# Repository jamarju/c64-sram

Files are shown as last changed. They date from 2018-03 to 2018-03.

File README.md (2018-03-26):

# Commodore 64 (C64C) SRAM replacement

This is a static RAM replacement for C64C chips U10 and U11 (motherboards assy no. 250469).

It may also work on assy no. 250466 (DRAM chips U9 and U10), but I have only tested it on a 250469 board.

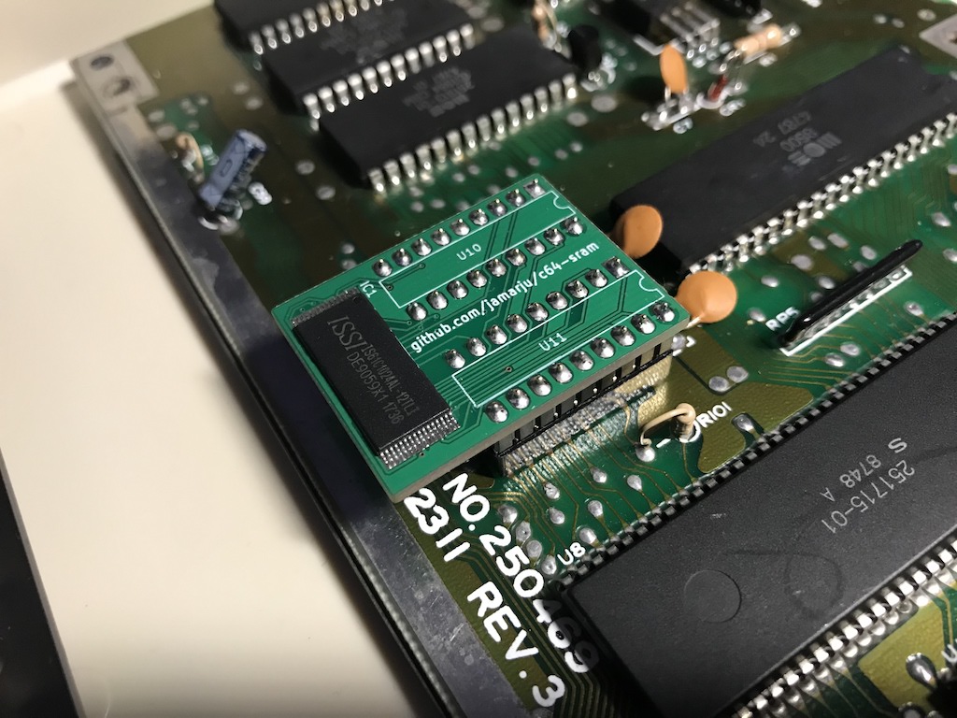
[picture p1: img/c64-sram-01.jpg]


It is based on [Gerrit4's design, originally posted at the lemon64 forum](http://www.lemon64.com/forum/viewtopic.php?p=773935#773935).

## Building

See [bom](bom/) and [gerber](gerber/) if you wish to build your own.

You can use any pin headers you find suitable but I suggest 0.50 mm round pin headers so as not to put too much stress on the sockets. They are easy to find on Aliexpress as "gold round male pin".

You can solder all 36 pins of U10 and U11 as in the pictures below, however only these 23 pins are strictly needed:

* U10: pins 2, 3, 15, 17, 18
* U11: all pins required

For soldering convenience and better board support I suggest soldering the following:

* U10: solder pins 2, 3, 15, 16, 17, 18
* U11: solder all pins

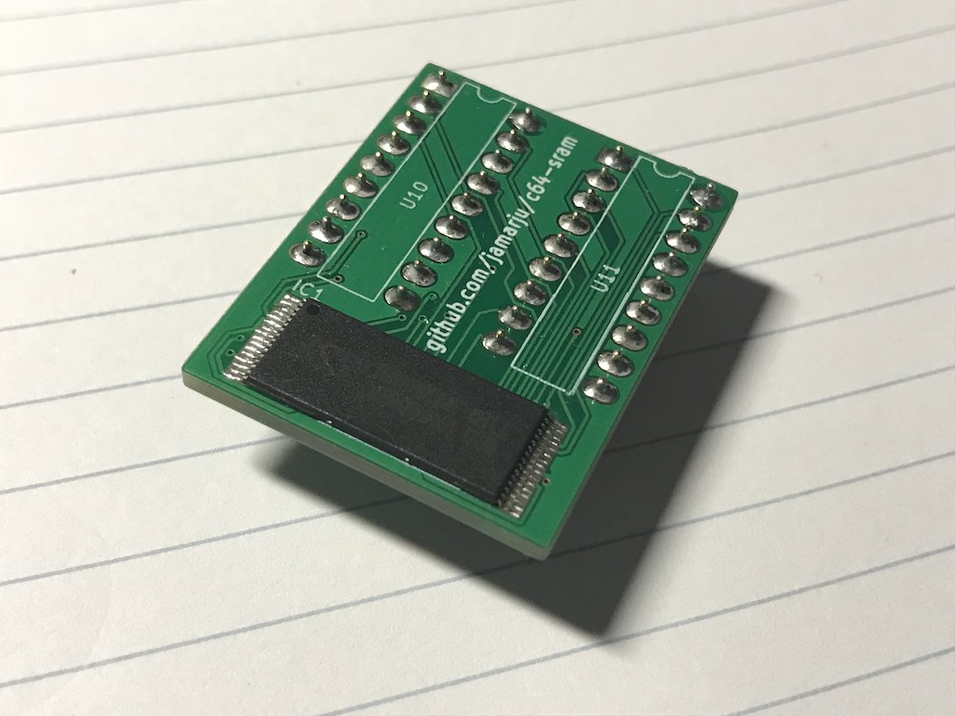
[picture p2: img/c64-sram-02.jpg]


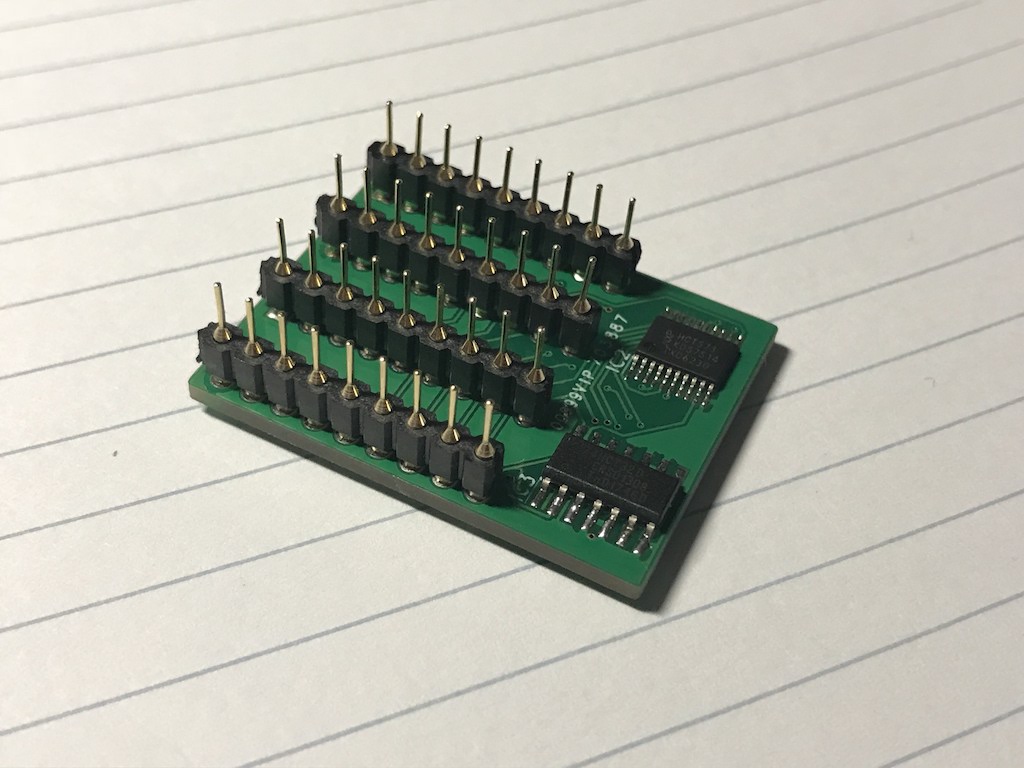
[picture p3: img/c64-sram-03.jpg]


## Thanks

Gerrit4 for the schematic design.

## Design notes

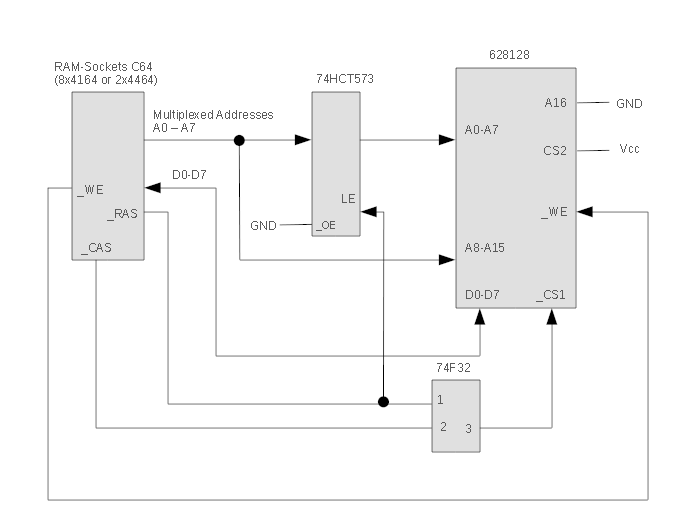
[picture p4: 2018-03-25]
img/RAM.gif

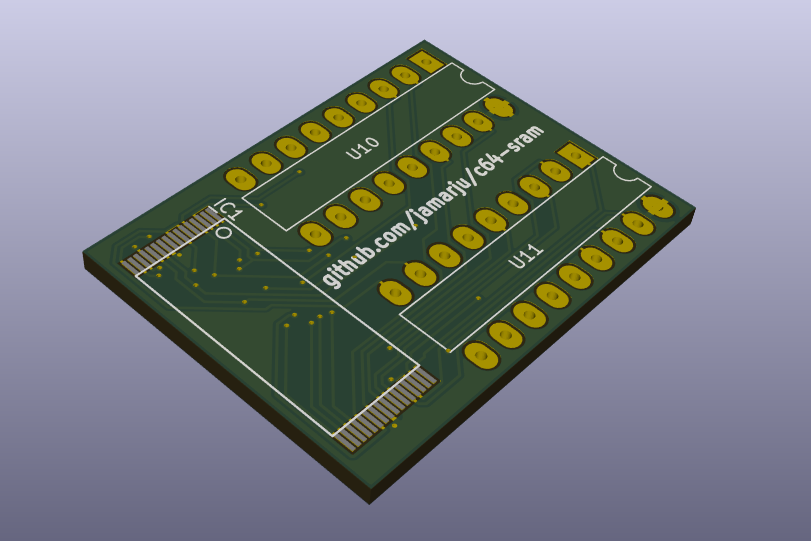
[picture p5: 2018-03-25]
img/kicad-3d.png

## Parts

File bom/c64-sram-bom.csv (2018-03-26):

Ref | Qty | Mfr. Code | Description
IC1 | 1 | IS61C1024AL-12TLI | SRAM chip 5V 12ns 32-pin TSOP-I (8x20 mm)
IC2 | 1 | 74HCT573PW,112 | Transparent latch x8, TSSOP-20 (body width 4.4 mm)
IC3 | 1 | 74HCT32D,653 | OR gate SO-14 (body width 3.9 mm)
U10, U11 | 24 | See README | Round pin header strip, 2.54 mm pitch, 0.5 mm contact width

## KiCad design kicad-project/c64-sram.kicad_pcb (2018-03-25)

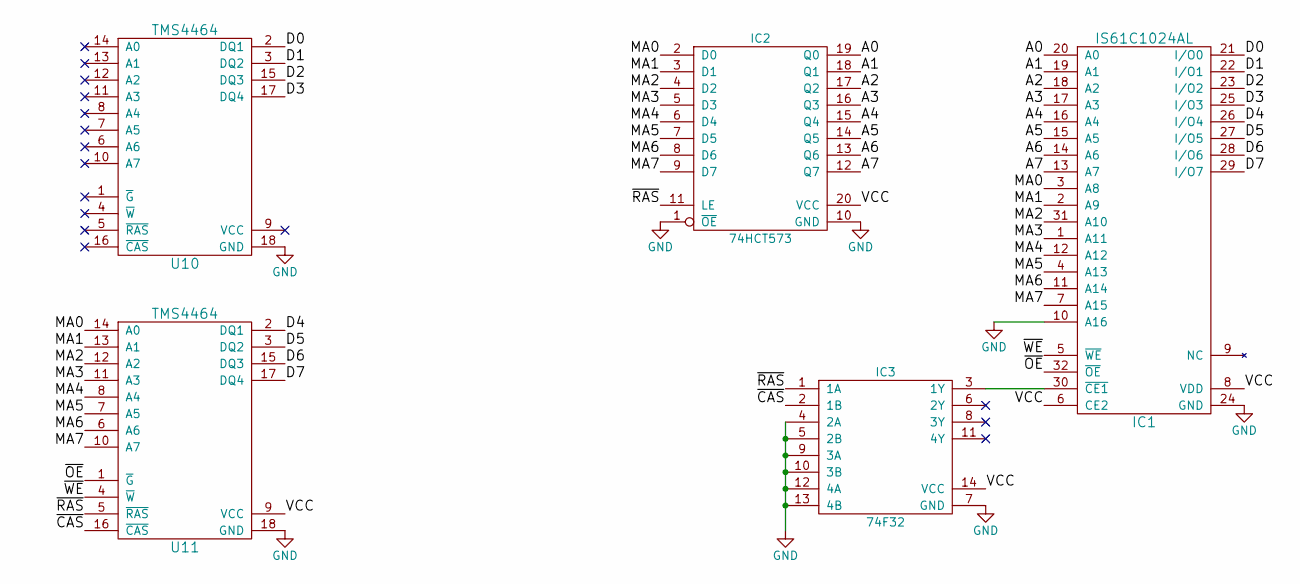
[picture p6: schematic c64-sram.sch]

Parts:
IC1: IS61C1024AL; TSOP_I_32L_8x20_p0.5
IC2: 74HCT573; TSSOP20_4.4x6.3_p0.65
IC3: 74F32; SOIC-14_6x8.65
U10, U11: TMS4464; DIP-18_W7.62mm_LongPads

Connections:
/A0: IC1.20 (A0), IC2.19 (Q0)
/A1: IC1.19 (A1), IC2.18 (Q1)
/A2: IC1.18 (A2), IC2.17 (Q2)
/A3: IC1.17 (A3), IC2.16 (Q3)
/A4: IC1.16 (A4), IC2.15 (Q4)
/A5: IC1.15 (A5), IC2.14 (Q5)
/A6: IC1.14 (A6), IC2.13 (Q6)
/A7: IC1.13 (A7), IC2.12 (Q7)
/D0: IC1.21 (I/O0), U10.2 (DQ1)
/D1: IC1.22 (I/O1), U10.3 (DQ2)
/D2: IC1.23 (I/O2), U10.15 (DQ3)
/D3: IC1.25 (I/O3), U10.17 (DQ4)
/D4: IC1.26 (I/O4), U11.2 (DQ1)
/D5: IC1.27 (I/O5), U11.3 (DQ2)
/D6: IC1.28 (I/O6), U11.15 (DQ3)
/D7: IC1.29 (I/O7), U11.17 (DQ4)
/MA0: IC1.3 (A8), IC2.2 (D0), U11.14 (A0)
/MA1: IC1.2 (A9), IC2.3 (D1), U11.13 (A1)
/MA2: IC1.31 (A10), IC2.4 (D2), U11.12 (A2)
/MA3: IC1.1 (A11), IC2.5 (D3), U11.11 (A3)
/MA4: IC1.12 (A12), IC2.6 (D4), U11.8 (A4)
/MA5: IC1.4 (A13), IC2.7 (D5), U11.7 (A5)
/MA6: IC1.11 (A14), IC2.8 (D6), U11.6 (A6)
/MA7: IC1.7 (A15), IC2.9 (D7), U11.10 (A7)
/VCC: IC1.6 (CE2), IC1.8 (VDD), IC2.20 (VCC), IC3.14 (VCC), U11.9 (VCC)
/~CAS: IC3.2 (1B), U11.16 (~CAS)
/~OE: IC1.32 (~OE), U11.1 (~G)
/~RAS: IC2.11 (LE), IC3.1 (1A), U11.5 (~RAS)
/~WE: IC1.5 (~WE), U11.4 (~W)
GND: IC1.10 (A16), IC1.24 (GND), IC2.1 (~OE), IC2.10 (GND), IC3.4 (2A), IC3.5 (2B), IC3.7 (GND), IC3.9 (3A), IC3.10 (3B), IC3.12 (4A), IC3.13 (4B), U10.18 (GND), U11.18 (GND)
unnamed: IC1.30 (~CE1), IC3.3 (1Y)

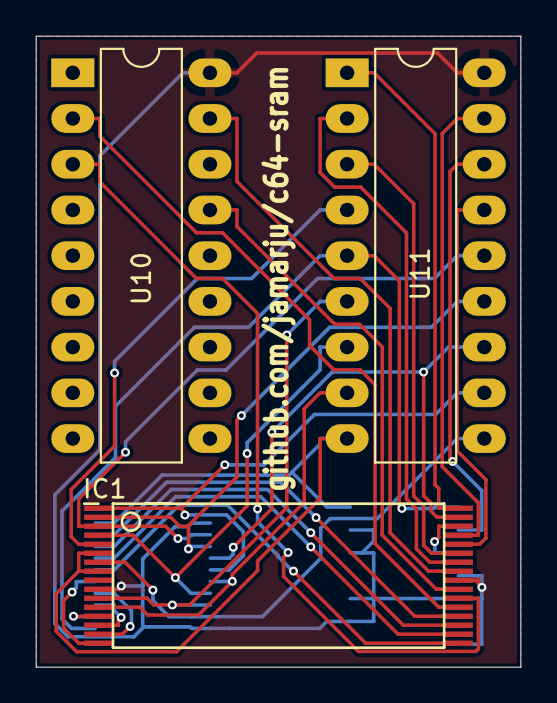
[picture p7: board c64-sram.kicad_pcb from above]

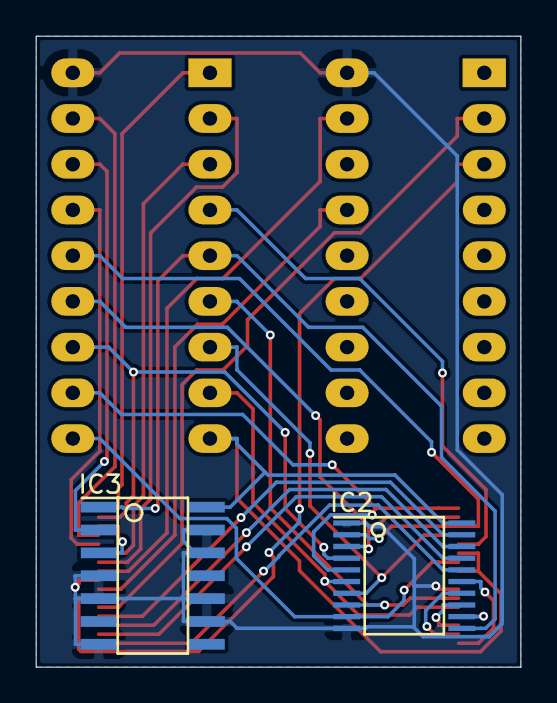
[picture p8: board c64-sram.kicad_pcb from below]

Board: 2 copper layers, 26.9 x 35.1 mm, 5 parts (2 on the bottom side), 31 nets.

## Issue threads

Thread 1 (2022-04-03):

No decoupling capacitors

seanch80, 2022-04-03:
Shouldn't there be decoupling capacitors next to the chips? There are on the SaRuMan-64 and diychris' longboard sram boards.

1c3d1v3r, 2022-04-03:
> Shouldn't there be decoupling capacitors next to the chips? There are on the SaRuMan-64 and diychris' longboard sram boards.

There's already caps on motherboard for the replaces DRAM chips. But generally it's better to have them on the same PCB next to the chips.

seanch80, 2022-04-03:
There should be room for some caps on the board. I've already ordered the boards and 5 sets of parts from the BOM. It's probably just fine the way it is, but I would prefer to have a revision with the decoupling caps on (at least 2). I think I will put this project on hold until either:
- I (as a 20 year eagle user) have learned kicad sufficiently to add them myself, or
- some vigilant hero online chooses to do it first. :)

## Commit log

2018-03-25 pin header soldering suggestions
    [c64-sram-bom.csv]
2018-03-26 pin header provider suggestions
    [c64-sram-bom.csv]
